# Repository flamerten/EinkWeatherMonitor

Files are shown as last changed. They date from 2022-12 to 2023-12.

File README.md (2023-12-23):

# Esp32 EinkWeatherMonitor
This E-Ink Weather Monitor uses a BME280 sensor to read and display temperature and humidity data every 15 minutes on an Eink Screen. A PCB for the components was designed, and was enclosed in a 3D printed case. 

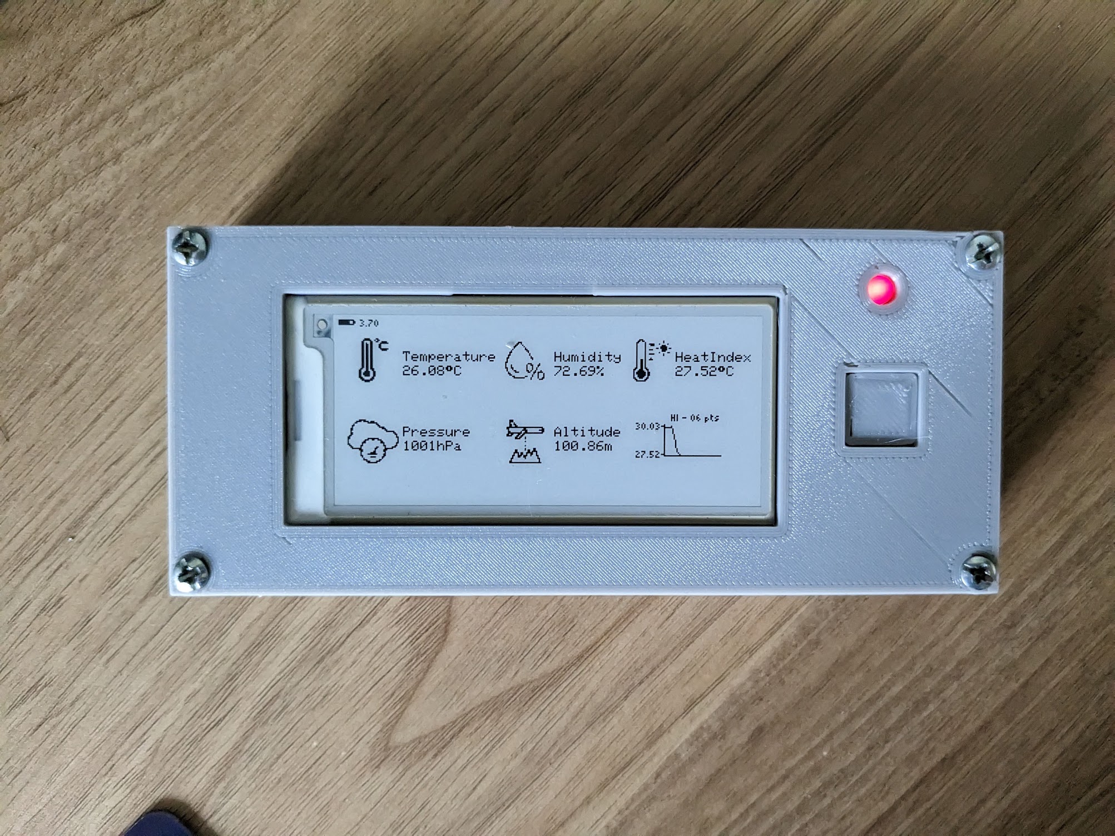
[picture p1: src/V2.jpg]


# Contents
## Firmware
Explanation and code for the ESP32, connected to the Eink screen and BME280
- [ESP32](#esp32)
- [Eink Screen](#eink-screen)

## Hardware
 - [STL Files](./casing/) with [Case Comments](#case-comments)
 - [PCB Files](./pcb/) (Manufactured by JLCPCB)
 - [Energy](#energy)

## Software
Instructions to set up bluehost to recieve weather data from the ESP32 and publish to an online graph. These were mainly adapted from this [source](https://randomnerdtutorials.com/visualize-esp32-esp8266-sensor-readings-from-anywhere/). This was depreceated because paying for Bluehost was expensive and after a while I didn't see value in storingw weather data over the long term. The PHP documentation can be found here, [Link](firmware/php/). The [Firmware](#firmware) section also goes over how to post data. The implementation can be found in this previous [commit](https://github.com/flamerten/EinkWeatherMonitor/tree/0d8b8b7bda3bd70d65bcf7df93bc7a092cfe990f)

# Firmware
## ESP32
An [Adafruit ESP32 Huzzah v2](https://www.adafruit.com/product/5400) was used because it could fit in the breadboard better and had Lipo charging capabilities. Hence, this could be used a more portable project.

The ESP32 code is simple. The BME280 sensor is wired to the ESP32 and the sensor data is posted in the format. Note that `serverName` is the post data website, for instance: https://example/post-data.php.

    WiFiClient client;
    HTTPClient http;
    http.begin(client, serverName);
    http.addHeader("Content-Type", "application/x-www-form-urlencoded");
    String httpRequestData = "api_key=" + apiKeyValue + "&value1=" + String(bme.readTemperature())
                           + "&value2=" + String(bme.readHumidity()) + "&value3=" + String(bme.readPressure()/100.0F) + "";
    Serial.print("httpRequestData: ");
    Serial.println(httpRequestData);
    
    int httpResponseCode = http.POST(httpRequestData);

I added the deep sleep functionality for it to get data every **10mins**. Hence the trend of data is better seen. With a maximum of 40 data points, we can see how the data changes over around 6 hours.

For the time function, I used the internal RTC memory and the NTP Client server to get the time which is printed on the Eink screen. There will be times that the post function does not work, or WiFi is not connected, and I still want to see the last reading. The NTP Client Server is initially used to get the time and is saved to RTC memory. If wifi is not connected, then the RTC memory is incremented by 10mins and that is displayed. 

Note that the RTC memory will be initialised on boot up to the assigned value. After that it uses past stored RTC values.

The Secrets.h file was used to protect personal data. To use my code, create a header file called `Secrets.h` and fill in the following detais.

    //Private info, in Gitignore

    const char* WIFI_SSID = "WIFI";
    const char* WIFI_PASSWORD = "WIFI_PASS";

    const char* OTA_SSID = "OTA_WIFI";
    const char* OTA_PASSWORD = "OTA_PASS";

    const char* BLUEHOST_POST = "BLUEHOST_POST";

    String ESP32_API_KEY = "PERSONAL_ESP32_API";

The USB port is only for charging the Huzzah. There is no data cable due to mistakes in the PCB. Hence, the push button is designed to push the ESP32 into OTA mode.

1) Push button will wake the ESP32 and connect to the OTA WiFI
2) From there, the IP address is printed on the Eink screen. Connect to IP_address/update over the OTA wifi to upload code over OTA.

## Eink Screen
I added an Eink screen to display the latest data. The [GxEPD2 Library](https://github.com/ZinggJM/GxEPD2) was used with the MH-ET 2.9" Live Epaper Display ([AliExpressLink](https://www.aliexpress.com/item/4001338269518.html?spm=a2g0o.order_list.order_list_main.5.1f7f1802g598H8)).

I used this [source](https://forum.arduino.cc/t/help-with-waveshare-epaper-display-with-adafruit-huzzah32-esp32-feather-board/574300/8) to set up the Epaper display. Its alot simpler than the example given in the GxEPD2 Library. The SPI wiring is also different from standard ESP32s and I thus had to remap the values and initialise it differently. However, this method is probably the neatest, even for future applications rather than the example given.

    #include <SPI.h>
    #include <GxEPD2_BW.h>

    #define EPD_BUSY  32  // to EPD BUSY
    #define EPD_CS    15  // to EPD CS
    #define EPD_RST   27 // to EPD RST
    #define EPD_DC    33 // to EPD DC
    #define EPD_SCK   5 // to EPD CLK
    #define EPD_MISO  21 // Master-In Slave-Out not used, as no data from display
    #define EPD_MOSI  19 // to EPD DIN

    //specific to eink screen
    GxEPD2_BW<GxEPD2_290_T94, GxEPD2_290_T94::HEIGHT> display(GxEPD2_290_T94(EPD_CS, EPD_DC, EPD_RST, EPD_BUSY));

    void setup(){
        SPI.begin(EPD_SCK, EPD_MISO, EPD_MOSI, EPD_CS);
        display.init(115200);
    }

Note that for this library, `display.init` initialises the `Serial.begin` function, and thus there is no need to call it again. Calling `Serial.begin(115200)` before the init will lead to the ESP32 hanging. This was discovered from this [source](https://forum.arduino.cc/t/waveshare-e-paper-displays-with-spi/467865/2552).

# Hardware
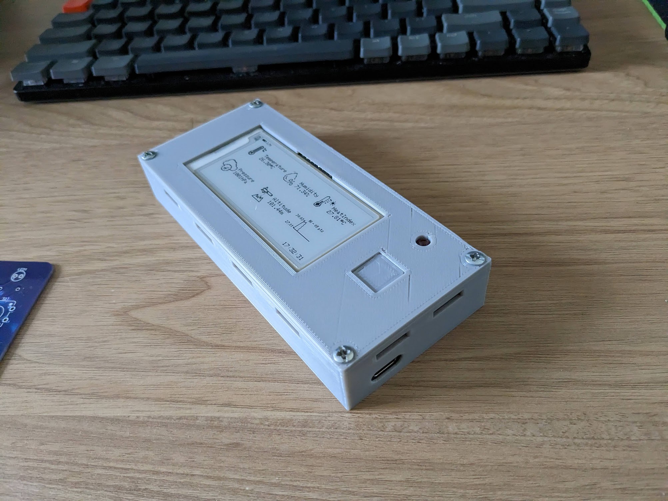
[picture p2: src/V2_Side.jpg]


## Case Comments
- [STL Files](./casing/) & [PCB Files](./pcb/)
- Holes at the side are used to allow ventillation from surrounding air, allowing the BME280 to read environmental data
- There was a mistake made in the PCB design, and I was thus forced to reroute the power cables to an external USB-C plug. Hence, OTA is used to program the board while the USB-C cable is used to charge the Lipo Battery.
- 4 M3 screws are threaded into the case to fix the cover over the bottom case.

## Energy
Energy usage was measured using a multimeter. One full cycle of waking up was noted to consume around 0.011mWh. So for a device that refreshes every 10minutes, the energy consumption is 13.65 mW/day. The device can thus last around 36 days on a 500mAH battery.

In designing the firmware, energy saving was taken into consideration. Both the BME sensor (line 514 of [esp32_bme.ino](firmware/esp32_bme/esp32_bme.ino)) and the ESP32 were designed to go to sleep after completeing their respective jobs.

Enabling or searching for WiFi can be energy consuming. Thus uploading sensor data and updating the time client data was done just before the appliance is about to go to sleep.

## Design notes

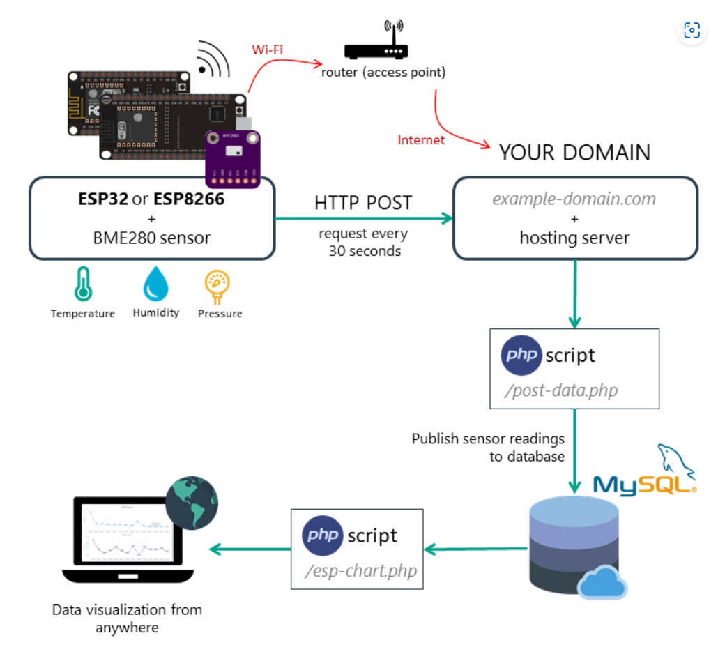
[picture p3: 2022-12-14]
src/network_architecture.png

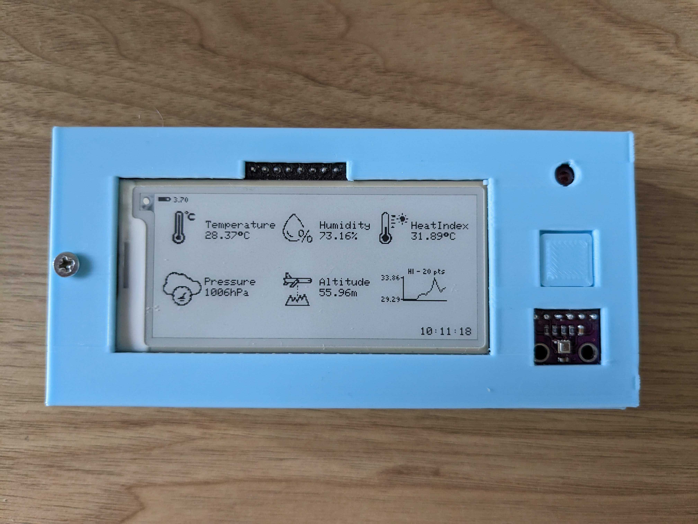
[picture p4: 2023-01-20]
src/FinalDesign.jpg

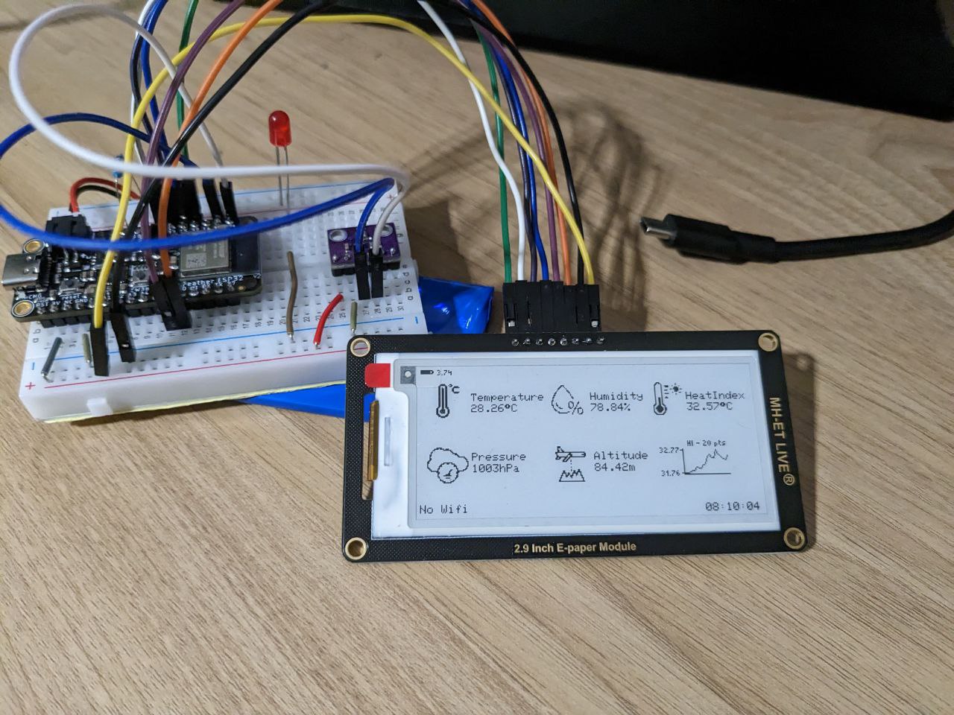
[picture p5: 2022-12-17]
src/SecondPrototype.jpg

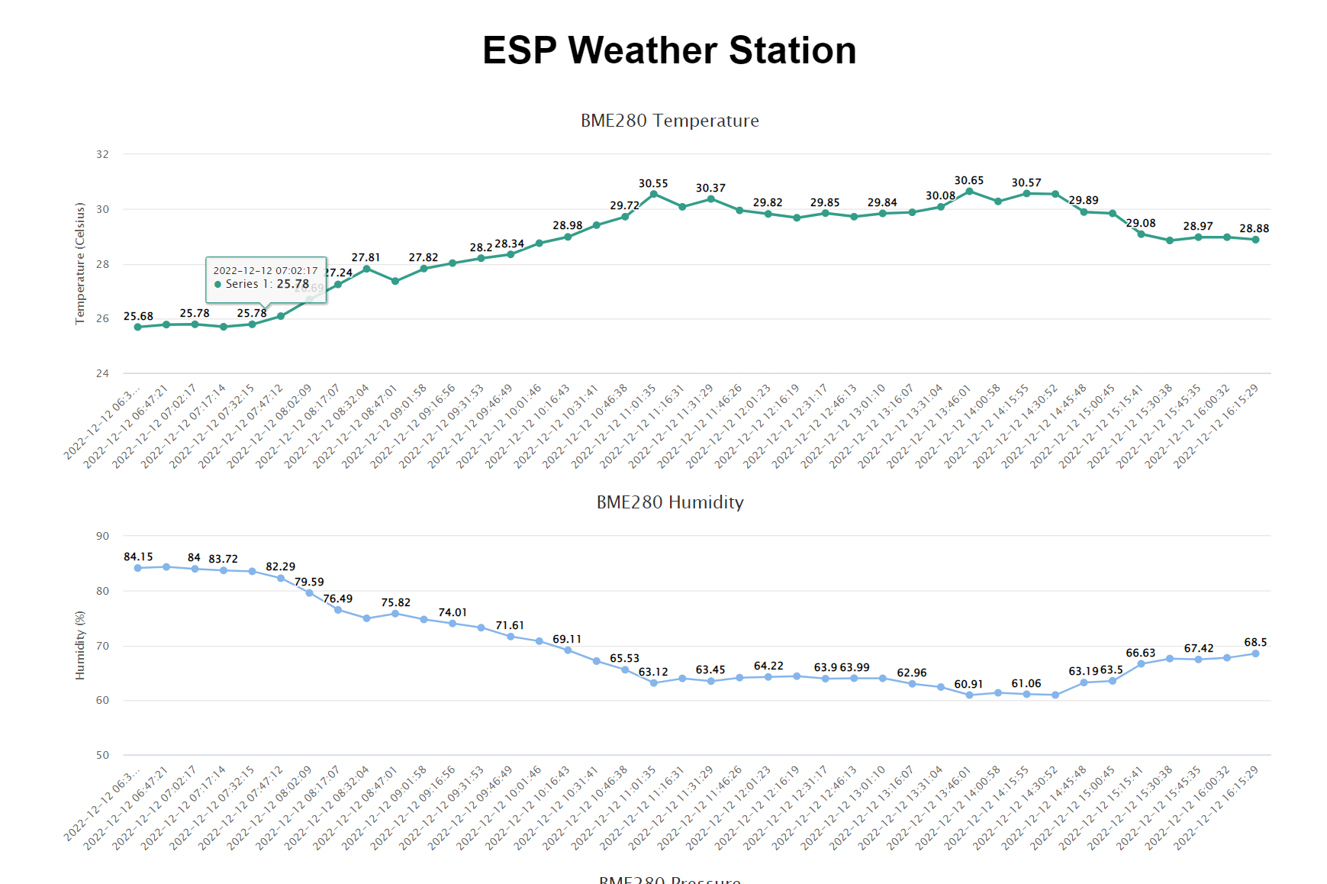
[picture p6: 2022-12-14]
src/example_chart.png

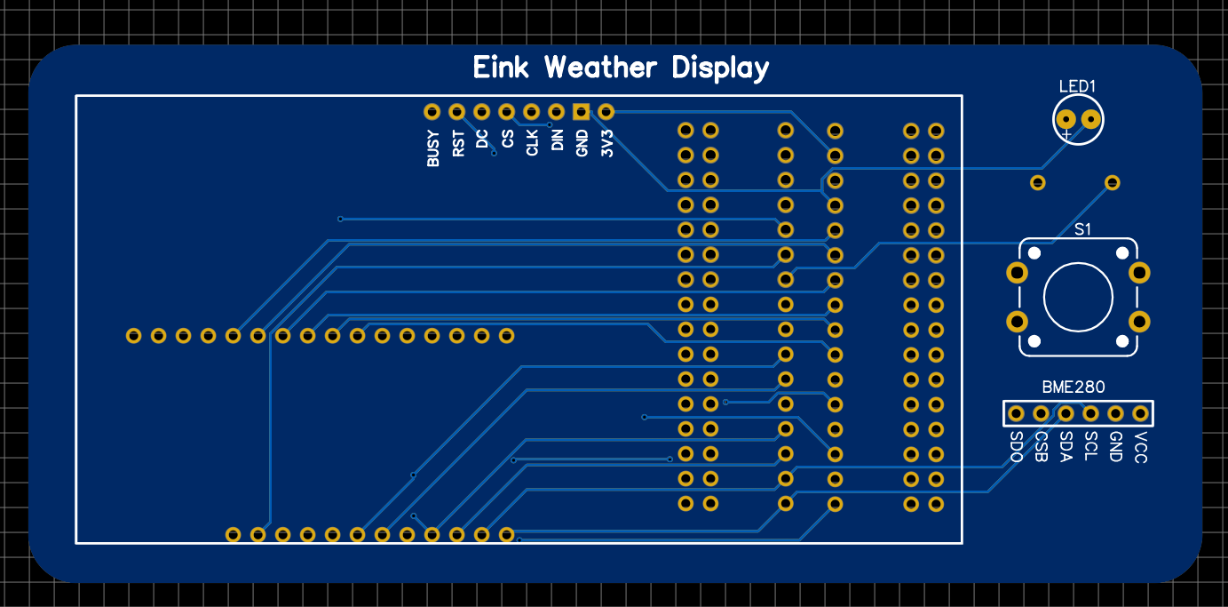
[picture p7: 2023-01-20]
src/pcb.png

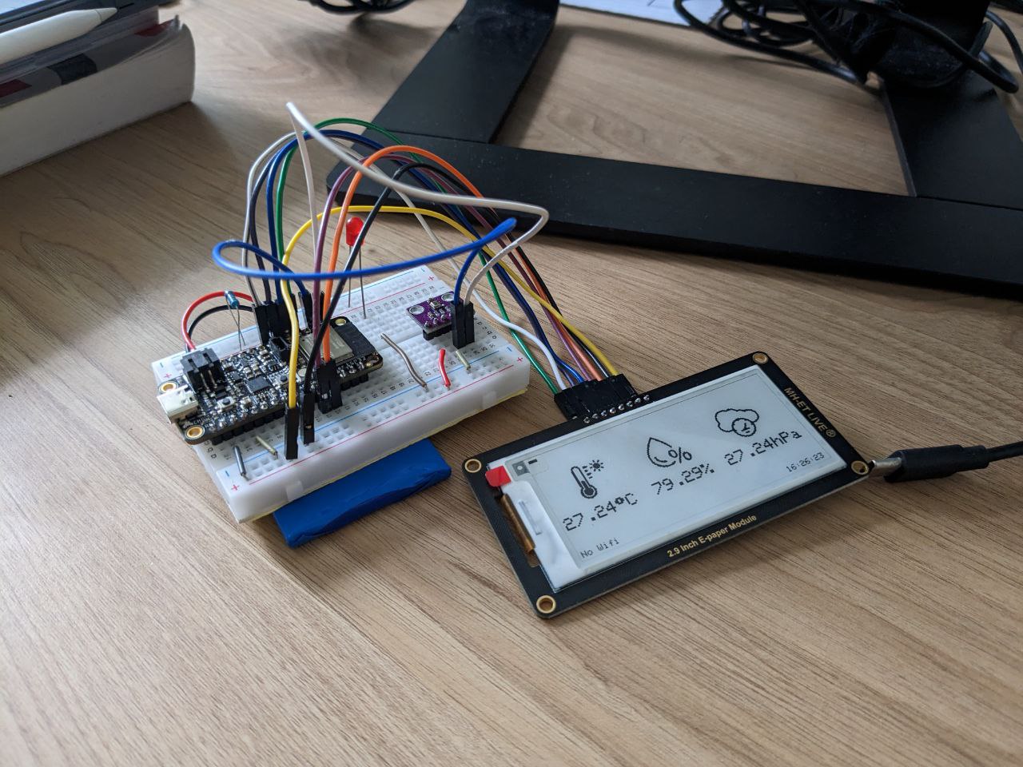
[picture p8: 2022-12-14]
src/FirstPrototype.jpg

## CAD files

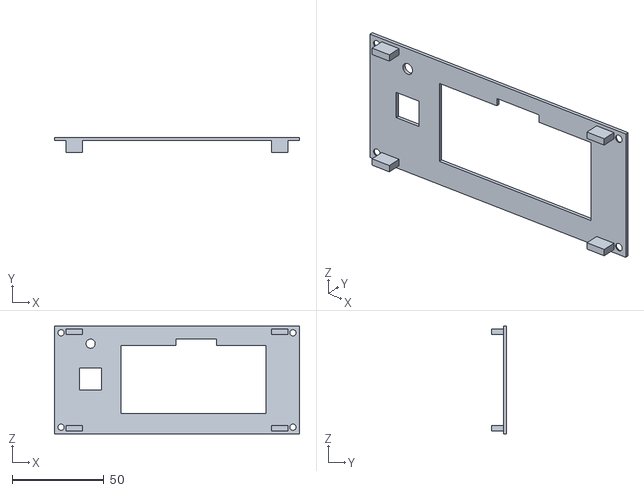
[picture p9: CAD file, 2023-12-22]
casing/5_TopCase.STL
133.3 x 8.00 x 58.5

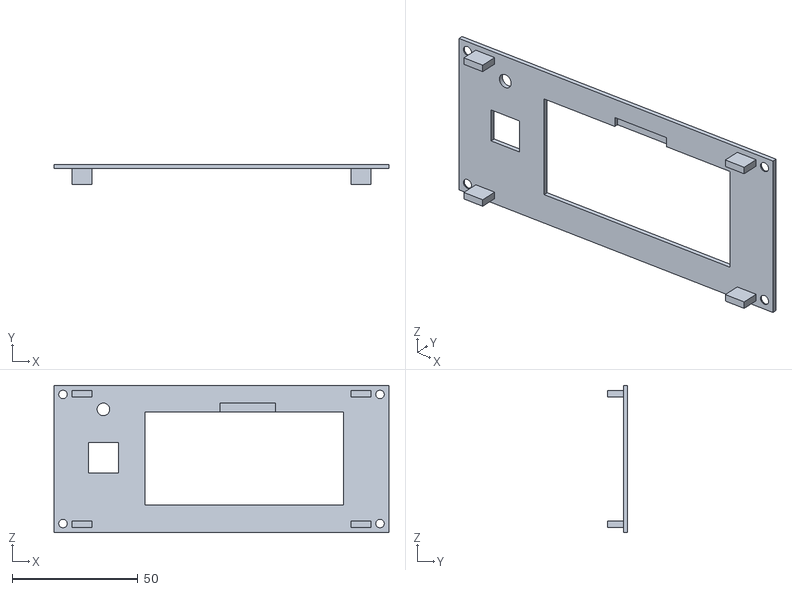
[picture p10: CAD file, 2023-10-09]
casing/6_TopCase.STL
133.3 x 8.15 x 58.5

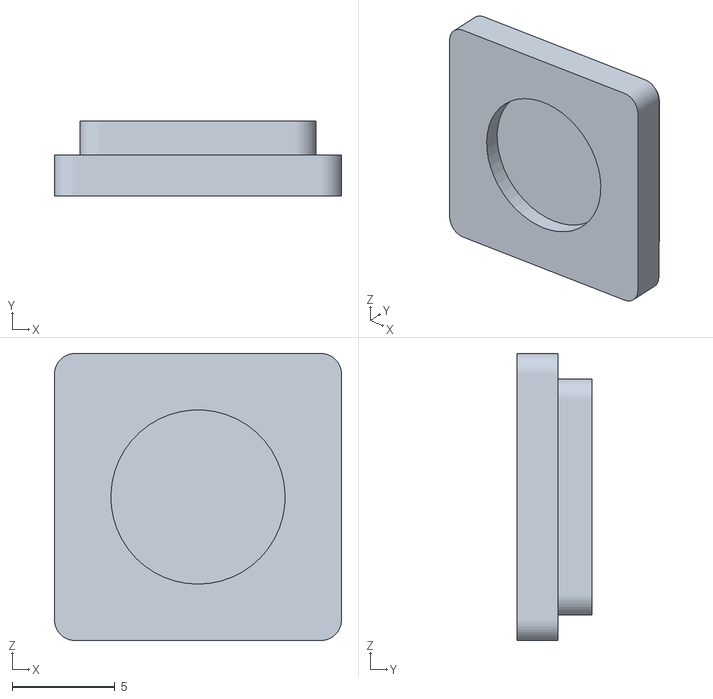
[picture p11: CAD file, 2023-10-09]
casing/6_Button.STL
14.0 x 3.65 x 14.0

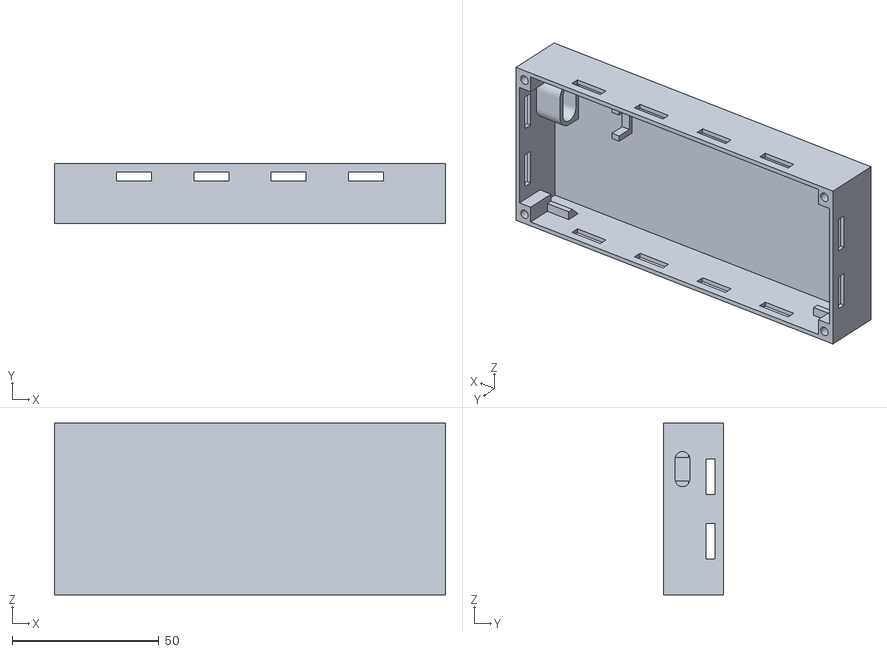
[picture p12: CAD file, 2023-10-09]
casing/5_BottomCase.STL
133.3 x 20.5 x 58.5

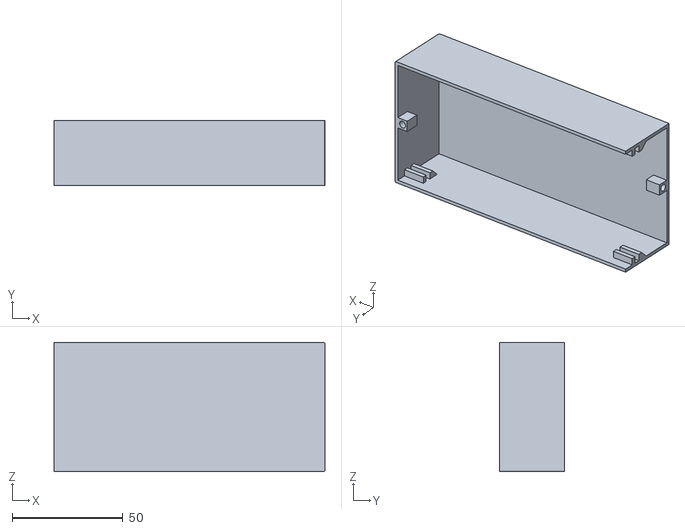
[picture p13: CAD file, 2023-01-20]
casing/4_BottomCase.STL
122.5 x 29.5 x 58.5

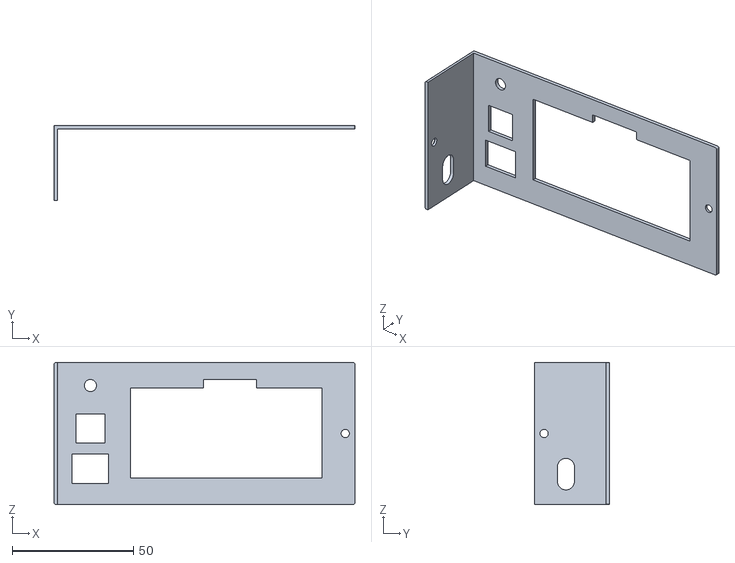
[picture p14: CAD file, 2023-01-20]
casing/4_TopCase.STL
124.0 x 31.0 x 58.5

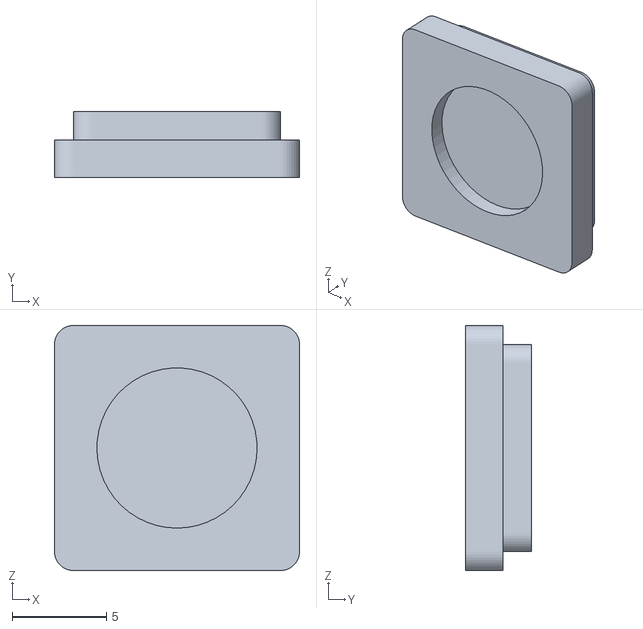
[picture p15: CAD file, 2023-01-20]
casing/4_Button.STL
13.0 x 3.50 x 13.0

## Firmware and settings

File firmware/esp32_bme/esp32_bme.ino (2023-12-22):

/*
  Samuel Yow
  ESp32 Eink Weather Monitor

  Upload data to cloud based on this tutorial by Rui Santos https://RandomNerdTutorials.com/visualize-esp32-esp8266-sensor-readings-from-anywhere/

*/

#define ESP32FEATHER //set as true if using feather
//#define ESP32DEVKIT

#include <WiFi.h>
#include <HTTPClient.h>
#include <Wire.h>
#include <Adafruit_Sensor.h>
#include <Adafruit_BME280.h>

#include <SPI.h>
#include <GxEPD2_BW.h>
#include <Fonts/Picopixel.h>

#include <NTPClient.h>
#include <WiFiUdp.h>

#include <AsyncTCP.h>
#include <ESPAsyncWebServer.h>
#include <AsyncElegantOTA.h>

#include "WeatherBitmap.h" //Local Bitmap
#include "Secrets.h" //For various private info
#define BAT_MONITOR 35

#define BAT_USED 1
#define USE_WIFI 1
#define USE_EINK 1

#define BUTTON 14
const uint64_t awake_time = 10 * 60 * 1000; //Awake after pressing button for 15mins
bool upload_mode = false;

// Replace with your network credentials
const char* ssid = WIFI_SSID;
const char* password = WIFI_PASSWORD;

const char* OTA_ssid = OTA_SSID;
const char* OTA_password = OTA_PASSWORD;


//Sensor
Adafruit_BME280 bme;
#define SEALEVELPRESSURE_HPA 1013.25
float Temperature, Humidity, Pressure, HeatIndex, Altitude;
//Set LEDPIN
#if defined(ESP32FEATHER)
  #define LED_PIN 2
#elif defined(ESP32DEVKIT)
  #define LED_PIN 13
#endif

//Connection Timings
#define uS_TO_S_FACTOR 1000000  /* Conversion factor for micro seconds to seconds */
#define SLEEP_MINUTES 15
const uint64_t TIME_TO_SLEEP = SLEEP_MINUTES*60;  
#define MAX_TRIES 10

//Eink
#define EPD_BUSY  32  // to EPD BUSY
#define EPD_CS    15  // to EPD CS
#define EPD_RST   27 // to EPD RST
#define EPD_DC    33 // to EPD DC
#define EPD_SCK   5 // to EPD CLK
#define EPD_MISO  19 // Master-In Slave-Out not used, as no data from display //21 // Had to swap due to errors in PCB
#define EPD_MOSI  21 // to EPD DIN  //19

//MH-ET Live 2.9" 128 X 296
//source: https://forum.arduino.cc/t/help-with-waveshare-epaper-display-with-adafruit-huzzah32-esp32-feather-board/574300/8 
GxEPD2_BW<GxEPD2_290_T94, GxEPD2_290_T94::HEIGHT> display(GxEPD2_290_T94(EPD_CS, EPD_DC, EPD_RST, EPD_BUSY));

//Timer Server and Records for Singapore
#define NTP_OFFSET  28800 // In seconds
#define NTP_INTERVAL 60 * 1000    // In miliseconds
#define NTP_ADDRESS  "sg.pool.ntp.org"

RTC_DATA_ATTR uint8_t RTC_Hours = 0;
RTC_DATA_ATTR uint8_t RTC_Minutes = 0;
RTC_DATA_ATTR uint8_t RTC_Seconds = 0;

//Graphing
#define MAX_GRAPH_PTS 20
RTC_DATA_ATTR float HeatIndexRecords[MAX_GRAPH_PTS]; //use less, so there are smoother points
RTC_DATA_ATTR uint8_t RecordFillPosition = 0;
RTC_DATA_ATTR bool FullCycle = false; //max length of data points have been collected

//OTA
AsyncWebServer server(80);

int16_t error_code = 0;
/* 0 No Error
 * 1 Wifi 
 * 100 or more is http error code
 */


void setupWebServer(){
  server.on("/", HTTP_GET, [](AsyncWebServerRequest *request) {
    request->send(200, "text/plain", "Hi! I am ESP32.");
  });

  AsyncElegantOTA.begin(&server);    // Start ElegantOTA
  server.begin();
  Serial.println("HTTP server started");
}

void initEink(){
  if(!USE_EINK) return;
  SPI.begin(EPD_SCK, EPD_MISO, EPD_MOSI, EPD_CS);
  delay(100);

  display.init(115200); // default 10ms reset pulse, e.g. for bare panels with DESPI-C02
  display.setRotation(3);     // landscape orientaion 
  display.setFullWindow();  
  display.setFont(); //display.setFont(&Picopixel);
  display.setTextColor(GxEPD_BLACK, GxEPD_WHITE); 
  display.firstPage();
}

void clearEink(){
  if(!USE_EINK) return;
  display.firstPage(); //Completely clear screen
  do
  {
    display.fillScreen(GxEPD_WHITE);
  }
  while (display.nextPage());
  display.fillScreen(GxEPD_WHITE); 
  delay(100);  
}

void PrintNoWifi(){
  if(!USE_EINK) return;
  else display.print("No Wifi");
}

void PrintAsyncIP(){
  if(!USE_EINK) return;
  if(WiFi.status() == WL_CONNECTED){
    display.print("Async:");
    display.print(WiFi.localIP());
    display.print("/update");
  }
  else display.print("No OTA Wifi");

}

void PrintBatLevel(){
  float BatPercent = ( analogRead(BAT_MONITOR) / 4096.0) * 3.3 * 2;
  Serial.printf("Bat Level: %f",BatPercent);
  Serial.println();

  if(!USE_EINK) return;
  const uint8_t height = 4;
  uint8_t width = 10;  
  //BatPercent
  float percentage = width * ( BatPercent - 3.0)/(3.8 - 3.0);
  uint8_t bat_w = percentage; //cast back to int
  
  bat_w = min(bat_w,width); //restrict to 8

  Serial.printf("Bat_w:%i",bat_w);
  Serial.println();
  //x,y,w,h
  display.drawRect(0,0,width+1,height,GxEPD_BLACK); //Bat Shape( + 1 cause its the outline)
  display.fillRect(0,0,bat_w,height,GxEPD_BLACK); //amt left
  display.fillRect(10,1,2,2,GxEPD_BLACK);

  display.setFont(&Picopixel);
  display.setTextSize(1);
  display.setCursor(15,height); //Picopixel starts at the bottomleft/centre?
  display.print(BatPercent,2); //2dp precision of bat level
  display.setFont(); //

}

float computeHeatIndex(float temperature, float humidity){
  /*
   *Source: https://github.com/adafruit/DHT-sensor-library/blob/master/DHT.cpp
   *Formula based on https://byjus.com/heat-index-formula/
   *Temp in degrees C, humidity %
   */

  float tempF = temperature * 1.8 + 32;
  float hi = 0.5 * (tempF + 61.0 + ((tempF - 68.0) * 1.2) + (humidity * 0.094));

  if (hi > 79) {
    hi = -42.379 + 2.04901523 * tempF + 10.14333127 * humidity +
         -0.22475541 * tempF * humidity +
         -0.00683783 * pow(tempF, 2) +
         -0.05481717 * pow(humidity, 2) +
         0.00122874 * pow(tempF, 2) * humidity +
         0.00085282 * tempF * pow(humidity, 2) +
         -0.00000199 * pow(tempF, 2) * pow(humidity, 2);

    if ((humidity < 13) && (tempF >= 80.0) &&
        (tempF <= 112.0))
      hi -= ((13.0 - humidity) * 0.25) *
            sqrt((17.0 - abs(tempF - 95.0)) * 0.05882);

    else if ((humidity > 85.0) && (tempF >= 80.0) &&
             (tempF <= 87.0))
      hi += ((humidity - 85.0) * 0.1) * ((87.0 - tempF) * 0.2);
  }  

  return (hi - 32) * 0.5556; //convert back to celcius


}

void printData(float temp, float hum,float pres){
  
  if(USE_EINK){
    display.drawInvertedBitmap(0,0,WeatherBitmapArray,296,128, GxEPD_BLACK); //Not too sure why it must be inverted?
    uint8_t y_row_1 = 22; uint8_t y_row_2 = 75; int y_increment = 10;
    uint8_t x_col_1 = 45; uint8_t x_col_2 = 152; uint8_t x_col_3 = 238; 

    //display.setCursor(0, 0);
    display.setTextSize(1);

    display.setCursor(x_col_1,y_row_1);                 display.print("Temperature");
    display.setCursor(x_col_1,y_row_1 + y_increment);   display.print(String(temp) + (char)247 + "C"); //degrees symbol

    display.setCursor(x_col_1,y_row_2);                 display.print("Pressure");
    display.setCursor(x_col_1,y_row_2 + y_increment);   display.print( String(int(pres)) + "hPa");

    display.setCursor(x_col_2,y_row_1);                 display.print("Humidity");
    display.setCursor(x_col_2,y_row_1 + y_increment);   display.print( String(hum) + "%");

    display.setCursor(x_col_2,y_row_2);                 display.print("Altitude");
    display.setCursor(x_col_2,y_row_2 + y_increment);   display.print( String(Altitude) + "m");

    display.setCursor(x_col_3,y_row_1);                 display.print("HeatIndex");
    display.setCursor(x_col_3,y_row_1 + y_increment);   display.print(String(HeatIndex) + (char)247 + "C"); //degrees symbol
  }


  //128 X 296  
  //String text = "00:00:00";
/*
  int16_t tbx, tby; uint16_t tbw, tbh; // boundary box window
  display.getTextBounds(text, 0, 0, &tbx, &tby, &tbw, &tbh); // it works for origin 0, 0, fortunately (negative tby!)
  uint16_t x = ((display.width() - tbw) / 2) - tbx;
  uint16_t y = ((display.height() - tbh) / 2) - tby;
  display.setFullWindow();
  display.firstPage();
  do
  {
    display.fillScreen(GxEPD_WHITE);
    display.setCursor(x, y);
    display.print(text);
  }
  while (display.nextPage());

  Serial.printf("width: %i ",tbw);
  Serial.printf("height: %i ",tbh);
  Serial.println();
*/

  //Serial.println(time_string);
  
  //display.display(); at the end
  
}

int mapf(double x, double in_min, double in_max, double out_min, double out_max)
{
    return (x - in_min) * (out_max - out_min) / (in_max - in_min) + out_min;
}

void PrintGraph(float HI){
  //UpdateValues
  HeatIndexRecords[RecordFillPosition] = HI;
  float DataSet[MAX_GRAPH_PTS]; //Not the most memory efficient i think

  //find max and min
  float max_hi = -90; float min_hi = 90; 
  uint8_t pos; uint8_t no_data_points = 0;
  uint16_t origin_x = 230;
  uint16_t origin_y = 73 ; //Top left corner
  uint8_t y_length = 22; uint8_t x_length = 41; //axis lengths
  String Title;

  
  if(FullCycle){
    for(int i = 0; i < MAX_GRAPH_PTS; i ++){
      pos = (RecordFillPosition + 1 + i)%MAX_GRAPH_PTS; //RecordFillPostion is the Current Point so the +1 point is the first point in the graph
      if(HeatIndexRecords[pos] > max_hi) max_hi = HeatIndexRecords[pos];
      if(HeatIndexRecords[pos] < min_hi) min_hi = HeatIndexRecords[pos];

      DataSet[no_data_points] = HeatIndexRecords[pos];
      no_data_points ++;
    }     
  }
  else{
    for(int pos = 0; pos <= RecordFillPosition; pos++){
      if(HeatIndexRecords[pos] > max_hi) max_hi = HeatIndexRecords[pos];
      if(HeatIndexRecords[pos] < min_hi) min_hi = HeatIndexRecords[pos];

      DataSet[no_data_points] = HeatIndexRecords[pos];
      no_data_points ++;    
    }
  }

  Serial.printf("Max: %f Min: %f",max_hi,min_hi); Serial.println();
  Serial.printf("No data points: %i",no_data_points); Serial.println();
  Serial.printf("HI: %f",HI); Serial.println();

  //Init Axis - also print the number of data points - maybe w title - maybe in terms of minutes?
  if(no_data_points < 10)  Title = "HI - 0" + String(no_data_points) + " pts";
  else                     Title = "HI - " + String(no_data_points) + " pts";

  if(USE_EINK){
    display.drawFastVLine(origin_x,origin_y,      y_length,GxEPD_BLACK); // Y axis;
    display.drawFastHLine(origin_x,origin_y + y_length ,x_length,GxEPD_BLACK); // X axis;

    
    //set max and min to be slightly below and above axis - mark them
    display.drawFastHLine(origin_x-2,origin_y + 1,3,GxEPD_BLACK); //Max 
    display.drawFastHLine(origin_x-2,origin_y + y_length - 1 ,3,GxEPD_BLACK); //Min

    display.setFont(&Picopixel);
    display.setTextSize(1);

    display.setCursor(235,70);
    display.print(Title);
    
    display.setCursor(origin_x-2-18,origin_y + 1 + 2); 
    display.print(max_hi,2); 

    display.setCursor(origin_x-2-18,origin_y + y_length - 1 + 2); //Picopixel starts at the bottomleft/centre?
    display.print(min_hi,2); 
  }

  Serial.printf("MaxCoord(%i,%i) MinCoord(%i,%i)",origin_x,origin_y+1,origin_x,origin_y+y_length-1);
  Serial.println();

  //Plot points
  
  int x,y, x_prev,y_prev;
  int increment  = (x_length - 1)/MAX_GRAPH_PTS;
  Serial.println("----------------------------");
  for(int i = 0; i < no_data_points; i++){
    x = origin_x + i*increment + 1;
    if(min_hi == max_hi) y = 10;
    else y = mapf(DataSet[i],min_hi,max_hi,0,20);
    
    if(y < 10) Serial.printf("Map Y: %i  ",y);
    else       Serial.printf("Map Y: %i ",y);
    
    y = origin_y + y_length -1 - y; 
    
    if(USE_EINK){
      display.drawPixel(x,y,GxEPD_BLACK);
      if(i!=0) display.drawLine(x,y,x_prev,y_prev,GxEPD_BLACK);
    }
    
    Serial.printf("HI: %f X: %i, Y: %i", DataSet[i],x,y); Serial.println();
    x_prev = x; y_prev = y;
  }

  Serial.println("----------------------------");
  

  //Update
  if(RecordFillPosition >= MAX_GRAPH_PTS-1){
    RecordFillPosition = 0;
    FullCycle = true;
  }
  else RecordFillPosition++;

}

void connectWifi(){
  WiFi.mode(WIFI_STA);
  uint32_t WifiConnectStart = millis();

  if(upload_mode) WiFi.begin(OTA_ssid, OTA_password);
  else            WiFi.begin(ssid, password);

  while ( (WiFi.status() != WL_CONNECTED) && (millis() - WifiConnectStart <= 5000)) { //try to connect for 5s
    delay(500);
    Serial.print(".");
  }

  if(WiFi.status() != WL_CONNECTED){
    error_code = 1;
    Serial.println("Unable to connect to Wifi");
  }
  if(upload_mode && error_code != 1) setupWebServer();

}

void updateBottom(String msg){
  display.setTextSize(1); //For Error codes
  display.setCursor(0,125); //numbers and words appear diff?
  display.setFont();
  display.setPartialWindow(0, 115, 296, 128);
  display.firstPage();

  String HoursString   = String(RTC_Hours) +":";
  if(RTC_Hours < 10)     HoursString = "0" + HoursString;
  String MinutesString = String(RTC_Minutes) +":";
  if(RTC_Minutes < 10)   MinutesString = "0" + MinutesString;
  String SecondsString = String(RTC_Seconds);
  if(RTC_Seconds < 10)   SecondsString = "0" + SecondsString;  
  
  String time_string = HoursString + MinutesString + SecondsString;

  do{
    display.fillScreen(GxEPD_WHITE);
    display.setCursor(0,120); //numbers and words appear diff?
    display.println(msg);

    display.setCursor(296-50,128-8); //Calculate height and width to put at bottom right
    display.print(time_string);
  }while(display.nextPage());
}

void setup() {
  if(!USE_EINK) Serial.begin(115200); //will hang the esp32 if used with epaper display

  initEink();
  pinMode(BAT_MONITOR,INPUT);
  Serial.printf("Deep Sleep set up for %is",TIME_TO_SLEEP);
  Serial.println();

  esp_sleep_wakeup_cause_t wakeup_cause = esp_sleep_get_wakeup_cause();

  upload_mode = (wakeup_cause == ESP_SLEEP_WAKEUP_EXT0);
  Serial.printf("Wakeup Cause %i:",wakeup_cause);
  
  
  #if defined(ESP32FEATHER)
    Wire.begin(22,20);
    delay(1000); //no need anything if normal wire
  #endif

  // (you can also pass in a Wire library object like &Wire2)
  bool status = bme.begin(0x76);
  if (!status) {
    Serial.println("Could not find a valid BME280 sensor, check wiring or change I2C address!");
    display.setTextSize(2);
    display.println("BME Sensor error");
    display.display();
    esp_deep_sleep_start(); // Hope to reset 
  }
  //Weather Monitoring Mode
  bme.setSampling(Adafruit_BME280::MODE_FORCED, // Forced Measurements - perform one measurement, store and then sleep
                  Adafruit_BME280::SAMPLING_X1, // temperature
                  Adafruit_BME280::SAMPLING_X1, // pressure
                  Adafruit_BME280::SAMPLING_X1, // humidity
                  Adafruit_BME280::FILTER_OFF   );

  Serial.print("RTC Memory -> ");
  Serial.printf("%i:%i:%i",RTC_Hours,RTC_Minutes,RTC_Seconds);
  Serial.println();

  bme.takeForcedMeasurement();
  Temperature = bme.readTemperature();
  Humidity = bme.readHumidity();
  Pressure = bme.readPressure()/100.0F; //in hPa
  HeatIndex = computeHeatIndex(Temperature,Humidity); //HeatIndex = bme.readHeatIndex(true); - pending push request
  Altitude = bme.readAltitude(SEALEVELPRESSURE_HPA);

  //Increment RTC and then print it to the Eink Device
  if(upload_mode) RTC_Minutes = RTC_Minutes + SLEEP_MINUTES/2; //Averages to about half, since upload mode does not occur at 10mins 
  else            RTC_Minutes = RTC_Minutes + SLEEP_MINUTES;
  
  if(RTC_Minutes >= 60){
    RTC_Minutes = RTC_Minutes%60;
    RTC_Hours   = (RTC_Hours + 1)%24;
  }

  //Display
  if(USE_EINK){
    do{
      display.fillScreen(GxEPD_WHITE); //Clear screen
      printData(Temperature,Humidity,Pressure); //includes the time as well
      if(BAT_USED) PrintBatLevel();

      PrintGraph(HeatIndex);
    }
    while(display.nextPage());

    display.display();
  }
  else{
      printData(Temperature,Humidity,Pressure); //includes the time as well
      if(BAT_USED) PrintBatLevel();
      PrintGraph(HeatIndex);
  }

  if((wakeup_cause == ESP_SLEEP_WAKEUP_UNDEFINED) || (wakeup_cause == ESP_SLEEP_WAKEUP_EXT0)){
    connectWifi(); //Only look for wifi from the start.

    if(error_code != 1){
      // Update internal clock only when connected to WiFi
      Serial.println("Updating TimeClient");
      
      WiFiUDP ntpUDP;
      NTPClient timeClient(ntpUDP, NTP_ADDRESS, NTP_OFFSET, NTP_INTERVAL);
      
      uint8_t TC_Updates = 5;
      
      while(!timeClient.update()){
        timeClient.forceUpdate();
        TC_Updates--;
        if(TC_Updates <= 0){
          error_code = 2;
          break;
        }
      }
  
      if(error_code == 0){ // no errors 
        RTC_Hours = timeClient.getHours();
        RTC_Minutes = timeClient.getMinutes();
        RTC_Seconds = timeClient.getSeconds();
        Serial.println("TimeClient Updated");
      }
      else{
        Serial.println("Time Client failed to update"); //Simply use RTC
      }
    }

  }
  

  
  if(upload_mode && error_code != 1)            updateBottom("Async:" + (WiFi.localIP()).toString() + "/update");
  else if((upload_mode) && (error_code == 1))   updateBottom("No OTA Wifi");
  else if(error_code == 1)                      updateBottom("No Wifi");
  else if(error_code == 2)                      updateBottom("TimeClient Error");
  else if(error_code != 0)                      updateBottom("HTTP Error:" + String(error_code));
  else                                          updateBottom(""); //No errors  - error code = 0, so empty string is good

  esp_sleep_enable_ext0_wakeup(GPIO_NUM_14, LOW); 
  esp_sleep_enable_timer_wakeup(TIME_TO_SLEEP * uS_TO_S_FACTOR);
  if(!upload_mode){
    Serial.println("Going to sleep");
    display.powerOff();

    esp_deep_sleep_start();
  }
  
}

void loop() {
  //If here it keeps checking the wifi manager until the awake time exceeds
  if( (millis() > awake_time) || (digitalRead(BUTTON) == LOW)){
    updateBottom("No Upload");

    Serial.println("Going to sleep");
    display.powerOff();
    esp_deep_sleep_start();
  }

}

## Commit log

2022-12-14 First Working Prototype
2022-12-15 fix pressure bug
2022-12-15 Interface Improvement
    - Change Battery Symbol
    - Added Heat Index and Altitude
2022-12-17 Version 2.0
    - Shifted various components to include Heat Index and Altitude
    - Added option to not use WiFi or the Eink Screen
    - Implemented Heat Index Graph
    - Added Battery Voltage
2023-01-20 Reorganise files and updated report
    casing + pcb
    [4_BottomCase.STL, 4_Button.STL, 4_TopCase.STL]
2023-01-22 Energy Saving
    moved wifi connection to after Eink update, and measured the current usage. Updated this on the main README file.
2023-10-09 new comments, add new case pics
    [4_BottomCase.STL, 4_Button.STL, 4_TopCase.STL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]
2023-12-22 change cad files
    [4_BottomCase.STL, 4_Button.STL, 4_TopCase.STL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]
